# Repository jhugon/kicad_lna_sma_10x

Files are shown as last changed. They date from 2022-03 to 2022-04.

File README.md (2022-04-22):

# Low Noise Amplifier SMA 10x Board in KiCAD

This KiCad board is a low noise amplifier with SMA input and output.

- 100 kHz to 20 MHz
- 10 times amplitude amplification
- ≤ 100 µV RMS noise
- AC coupled input

## Notes on Performance as-built

I've been setting +/- 5 V supplies, 20 mA current limit, with +/- 6V OVP and 25 mA OCP.

- Idle current: 9 mA with +/- 5 V supplies
- Current draw rises above 20 mA for large signals
- Noise 1478 µV RMS at output (without subtracting noise floor), with a broad bump around 8-10 MHz in the FFT
- In trying to analyze with a square wave, the AC-coupling low-pass filter frequency seems
  quite high compared to the bandwidth. Maybe it should be at 10 kHz instead of
  100 kHz?
- Sin response:
    - Gain peaks ~ 9 MHz at 17 dB
    - Gain -3 dB from peak a little above 10 MHz
- Step response:
    - 10-90% rise time: 22 ns
    - 0-99% rise time: 32 ns
    - Overshoot: 28%
    - 1 pct settling time: ~200 ns
- Hooked up to SiPM and LED pulser:
    - Detect pulses with 10s of mV peak heights
    - Ringing is evident, lasts ~ 250 ns
    - Pulse width 50-100 ns
    - Can't see pulse height quantization, it's just one big smeared gaussian

With 10 pF (leaded) decoupling cap soldered between U1 output and inverting input:

- Noise a bit lower than before; FFT is flat compared to a broad, low peak around 20 MHz before
- Sin response:
    - Gain max ~flat between 400 kHz and 100 MHz
    - Gain -3 dB from peak at 100 kHz and 3 MHz
- Step response:
    - Minimal overshoot/settling, probably overdamped now
    - 10-90% rise time: 112 ns
    - 0-99% rise time: 293 ns
    - Overshoot: <1%
    - 1 pct settling time: ~250 ns
- Hooked up to SiPM and LED pulser:
    - Pulse height seems lower than before
    - No ringing, maybe baseline is a bit lower on tail
    - Pulse width 100-150 ns
    - Can't see pulse height quantization, it's just one big smeared gaussian

## To-Do

- Decoupling cap(s) from V+ to V-?
- Compensation cap between gain-amp out and in-?
- Lower input blocking filter freq?
- Forgot about factor of 1/2 from 50 Ohm termination voltage divider--need extra factor of 2 gain
- Add input/output labels on SMAs
- Add +/- signs on DC in
- SMA terminator for noise measurements

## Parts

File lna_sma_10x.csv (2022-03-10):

Source: | /home/jhugon/kicad/lna_sma_10x/lna_sma_10x.kicad_sch
Date: | Thu 10 Mar 2022 11:07:08 AM CST
Tool: | Eeschema 6.0.2-378541a8eb~116~ubuntu20.04.1
Generator: | /usr/share/kicad/plugins/bom_csv_grouped_by_value.py
Component Count: | 20
Individual Components:
Item | Qty | Reference(s) | Value | LibPart | Footprint | Datasheet | Mfr | Mfr Part | Tol/Type
 |  | C1 | 10u | Device:C | Capacitor_SMD:C_1206_3216Metric_Pad1.33x1.80mm_HandSolder | https://www.mouser.com/datasheet/2/585/MLCC-1837944.pdf | Samsung | CL31A106KAHNNNF | 5%/X5R
 |  | C2 | 160p | Device:C | Capacitor_SMD:C_1206_3216Metric_Pad1.33x1.80mm_HandSolder | https://www.mouser.com/datasheet/2/40/C0GNP0_Dielectric-951274.pdf | Kyocera AVX | 12065A161JAT2A | 5%/C0G
 |  | C3 | 0.1u | Device:C | Capacitor_SMD:C_1206_3216Metric_Pad1.33x1.80mm_HandSolder | https://www.mouser.com/datasheet/2/585/MLCC-1837944.pdf | Samsung | CL31B104KBCNNND | 5%/X5R
 |  | C4 | 0.1u | Device:C | Capacitor_SMD:C_1206_3216Metric_Pad1.33x1.80mm_HandSolder | https://www.mouser.com/datasheet/2/585/MLCC-1837944.pdf | Samsung | CL31B104KBCNNND | 5%/X5R
 |  | C5 | 10u | Device:C | Capacitor_SMD:C_1206_3216Metric_Pad1.33x1.80mm_HandSolder | https://www.mouser.com/datasheet/2/585/MLCC-1837944.pdf | Samsung | CL31A106KAHNNNF | 5%/X5R
 |  | C6 | 0.1u | Device:C | Capacitor_SMD:C_1206_3216Metric_Pad1.33x1.80mm_HandSolder | https://www.mouser.com/datasheet/2/585/MLCC-1837944.pdf | Samsung | CL31B104KBCNNND | 5%/X5R
 |  | C7 | 0.1u | Device:C | Capacitor_SMD:C_1206_3216Metric_Pad1.33x1.80mm_HandSolder | https://www.mouser.com/datasheet/2/585/MLCC-1837944.pdf | Samsung | CL31B104KBCNNND | 5%/X5R
 |  | J1 | Conn_Coaxial | Connector:Conn_Coaxial | Connector_Coaxial:SMA_Amphenol_132289_EdgeMount | https://www.mouser.com/datasheet/2/18/1/amphs06501_1-2259276.pdf | Amphenol | 132289
 |  | J2 | Power In | New_Library:Power-NanoFit-01x03 | Connector_Molex:Molex_Nano-Fit_105313-xx03_1x03_P2.50mm_Horizontal | https://www.mouser.com/datasheet/2/276/1/1053131303_PCB_HEADERS-1373923.pdf | Molex | 105313-1303
 |  | J3 | Conn_Coaxial | Connector:Conn_Coaxial | Connector_Coaxial:SMA_Amphenol_132289_EdgeMount | https://www.mouser.com/datasheet/2/18/1/amphs06501_1-2259276.pdf | Amphenol | 132289
 |  | R1 | 10K | Device:R_US | Resistor_SMD:R_1206_3216Metric_Pad1.30x1.75mm_HandSolder | https://www.mouser.com/datasheet/2/427/crcwce3-1762584.pdf | Vishay | CRCW120610K0FKEBC | 1%
 |  | R2 | 10K | Device:R_US | Resistor_SMD:R_1206_3216Metric_Pad1.30x1.75mm_HandSolder | https://www.mouser.com/datasheet/2/427/crcwce3-1762584.pdf | Vishay | CRCW120610K0FKEBC | 1%
 |  | R3 | 50R | Device:R_US | Resistor_SMD:R_1206_3216Metric_Pad1.30x1.75mm_HandSolder | https://www.mouser.com/datasheet/2/427/crcwce3-1762584.pdf | Vishay | CRCW120649R9FKEAC | 5%
 |  | R4 | 500R | Device:R_US | Resistor_SMD:R_1206_3216Metric_Pad1.30x1.75mm_HandSolder | https://www.mouser.com/datasheet/2/427/crcwce3-1762584.pdf | Vishay | CRCW1206499RFKEAC | 1%
 |  | R5 | 3K3 | Device:R_US | Resistor_SMD:R_1206_3216Metric_Pad1.30x1.75mm_HandSolder | https://www.mouser.com/datasheet/2/427/crcwce3-1762584.pdf | Vishay | CRCW12063K32FKEAC | 1%
 |  | R6 | 100R | Device:R_US | Resistor_SMD:R_1206_3216Metric_Pad1.30x1.75mm_HandSolder | https://www.mouser.com/datasheet/2/427/crcwce3-1762584.pdf | Vishay | CRCW1206100RFKEAC | 5%
 |  | R7 | 1k2 | Device:R_US | Resistor_SMD:R_1206_3216Metric_Pad1.30x1.75mm_HandSolder | https://www.mouser.com/datasheet/2/427/crcwce3-1762584.pdf | Vishay | CRCW12061K20FKEAC | 1%
 |  | R8 | 50R | Device:R_US | Resistor_SMD:R_1206_3216Metric_Pad1.30x1.75mm_HandSolder | https://www.mouser.com/datasheet/2/427/crcwce3-1762584.pdf | Vishay | CRCW120649R9FKEAC | 5%
 |  | U1 | LT1722xS8 | New_Library:LT1722xS8 | Package_SO:SOIC-8_3.9x4.9mm_P1.27mm | https://www.analog.com/media/en/technical-documentation/data-sheets/172234fb.pdf | Analog Devices | LT1722CS8#PBF
 |  | U2 | BUF602xD | Amplifier_Buffer:BUF602xD | Package_SO:SOIC-8_3.9x4.9mm_P1.27mm | http://www.ti.com/lit/ds/symlink/buf602.pdf | Texas Instruments | BUF602ID
Collated Components:
Item | Qty | Reference(s) | Value | LibPart | Footprint | Datasheet | Mfr | Mfr Part | Tol/Type
1 | 2 | C1, C5 | 10u | Device:C | Capacitor_SMD:C_1206_3216Metric_Pad1.33x1.80mm_HandSolder | https://www.mouser.com/datasheet/2/585/MLCC-1837944.pdf | Samsung | CL31A106KAHNNNF | 5%/X5R
2 | 1 | C2 | 160p | Device:C | Capacitor_SMD:C_1206_3216Metric_Pad1.33x1.80mm_HandSolder | https://www.mouser.com/datasheet/2/40/C0GNP0_Dielectric-951274.pdf | Kyocera AVX | 12065A161JAT2A | 5%/C0G
3 | 4 | C3, C4, C6, C7 | 0.1u | Device:C | Capacitor_SMD:C_1206_3216Metric_Pad1.33x1.80mm_HandSolder | https://www.mouser.com/datasheet/2/585/MLCC-1837944.pdf | Samsung | CL31B104KBCNNND | 5%/X5R
4 | 2 | J1, J3 | Conn_Coaxial | Connector:Conn_Coaxial | Connector_Coaxial:SMA_Amphenol_132289_EdgeMount | https://www.mouser.com/datasheet/2/18/1/amphs06501_1-2259276.pdf | Amphenol | 132289
5 | 1 | J2 | Power In | New_Library:Power-NanoFit-01x03 | Connector_Molex:Molex_Nano-Fit_105313-xx03_1x03_P2.50mm_Horizontal | https://www.mouser.com/datasheet/2/276/1/1053131303_PCB_HEADERS-1373923.pdf | Molex | 105313-1303
6 | 2 | R1, R2 | 10K | Device:R_US | Resistor_SMD:R_1206_3216Metric_Pad1.30x1.75mm_HandSolder | https://www.mouser.com/datasheet/2/427/crcwce3-1762584.pdf | Vishay | CRCW120610K0FKEBC | 1%
7 | 2 | R3, R8 | 50R | Device:R_US | Resistor_SMD:R_1206_3216Metric_Pad1.30x1.75mm_HandSolder | https://www.mouser.com/datasheet/2/427/crcwce3-1762584.pdf | Vishay | CRCW120649R9FKEAC | 5%
8 | 1 | R4 | 500R | Device:R_US | Resistor_SMD:R_1206_3216Metric_Pad1.30x1.75mm_HandSolder | https://www.mouser.com/datasheet/2/427/crcwce3-1762584.pdf | Vishay | CRCW1206499RFKEAC | 1%
9 | 1 | R5 | 3K3 | Device:R_US | Resistor_SMD:R_1206_3216Metric_Pad1.30x1.75mm_HandSolder | https://www.mouser.com/datasheet/2/427/crcwce3-1762584.pdf | Vishay | CRCW12063K32FKEAC | 1%
10 | 1 | R6 | 100R | Device:R_US | Resistor_SMD:R_1206_3216Metric_Pad1.30x1.75mm_HandSolder | https://www.mouser.com/datasheet/2/427/crcwce3-1762584.pdf | Vishay | CRCW1206100RFKEAC | 5%
11 | 1 | R7 | 1k2 | Device:R_US | Resistor_SMD:R_1206_3216Metric_Pad1.30x1.75mm_HandSolder | https://www.mouser.com/datasheet/2/427/crcwce3-1762584.pdf | Vishay | CRCW12061K20FKEAC | 1%
12 | 1 | U1 | LT1722xS8 | New_Library:LT1722xS8 | Package_SO:SOIC-8_3.9x4.9mm_P1.27mm | https://www.analog.com/media/en/technical-documentation/data-sheets/172234fb.pdf | Analog Devices | LT1722CS8#PBF
13 | 1 | U2 | BUF602xD | Amplifier_Buffer:BUF602xD | Package_SO:SOIC-8_3.9x4.9mm_P1.27mm | http://www.ti.com/lit/ds/symlink/buf602.pdf | Texas Instruments | BUF602ID

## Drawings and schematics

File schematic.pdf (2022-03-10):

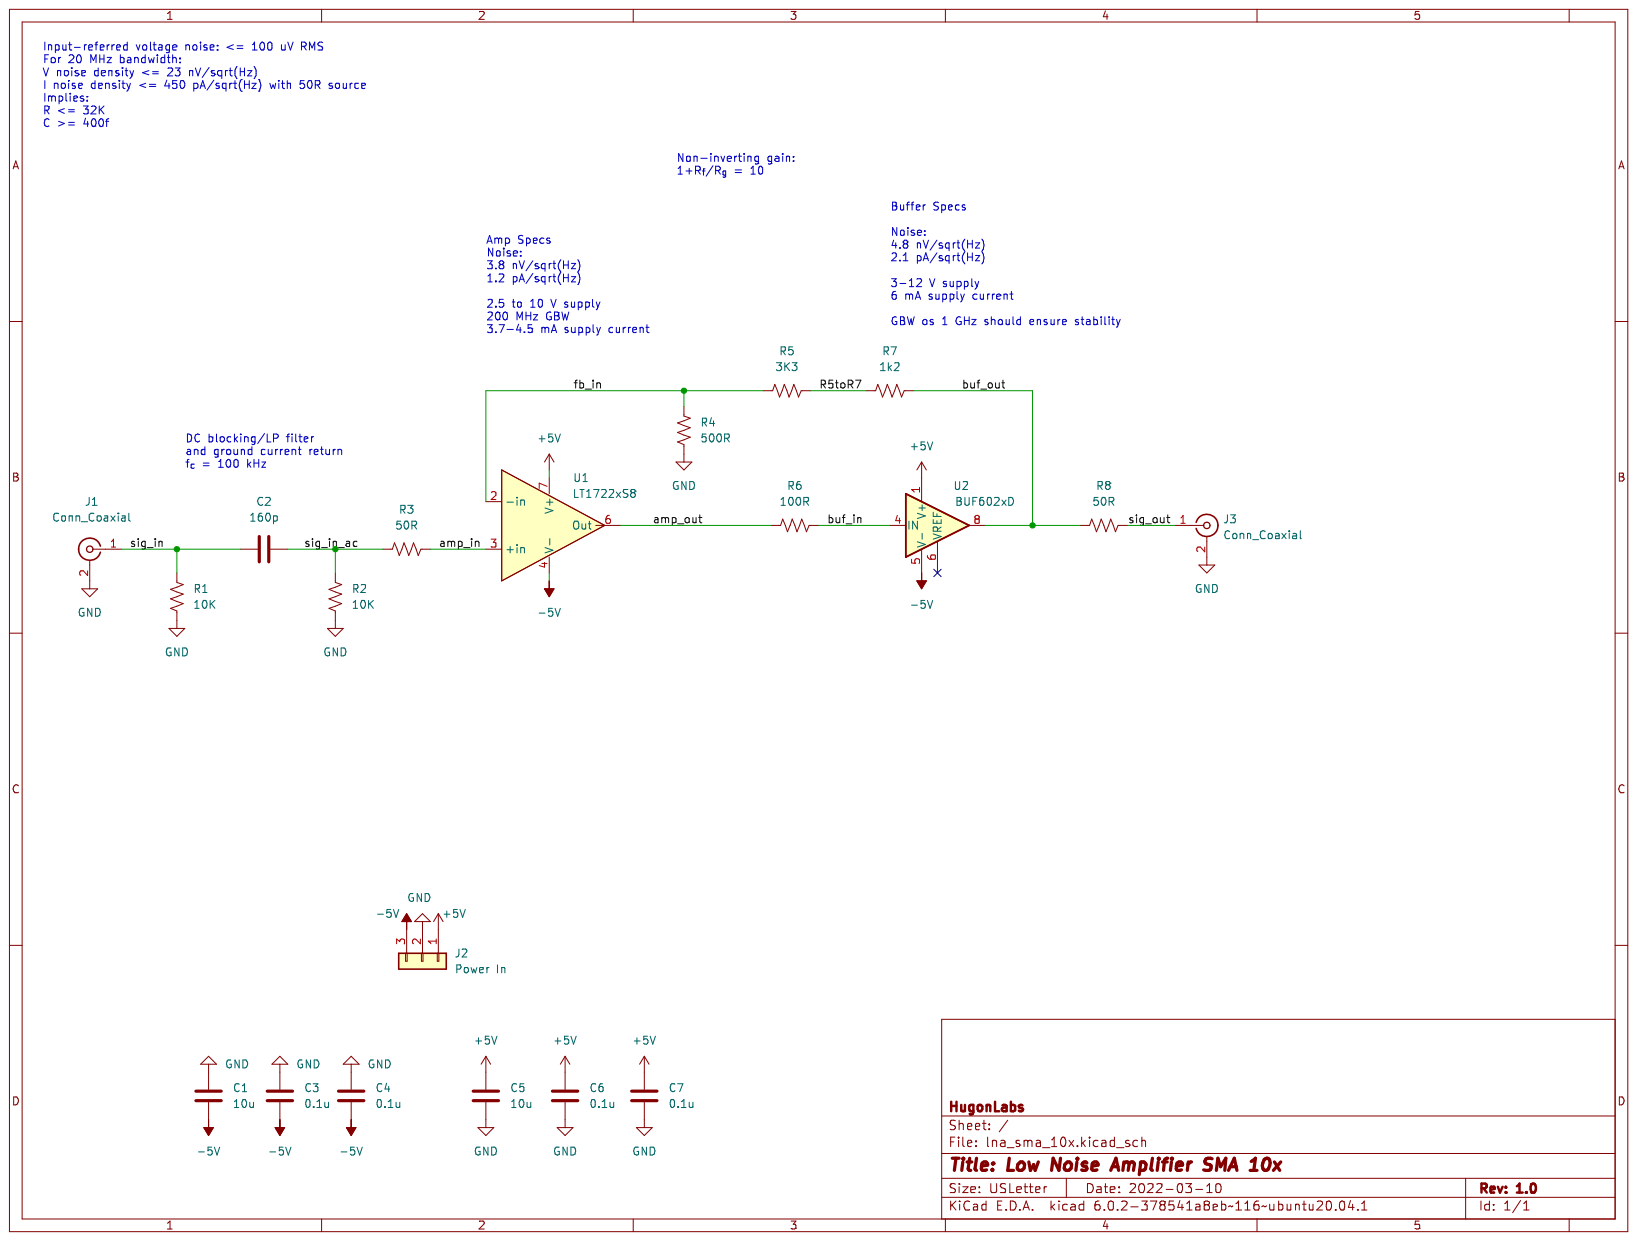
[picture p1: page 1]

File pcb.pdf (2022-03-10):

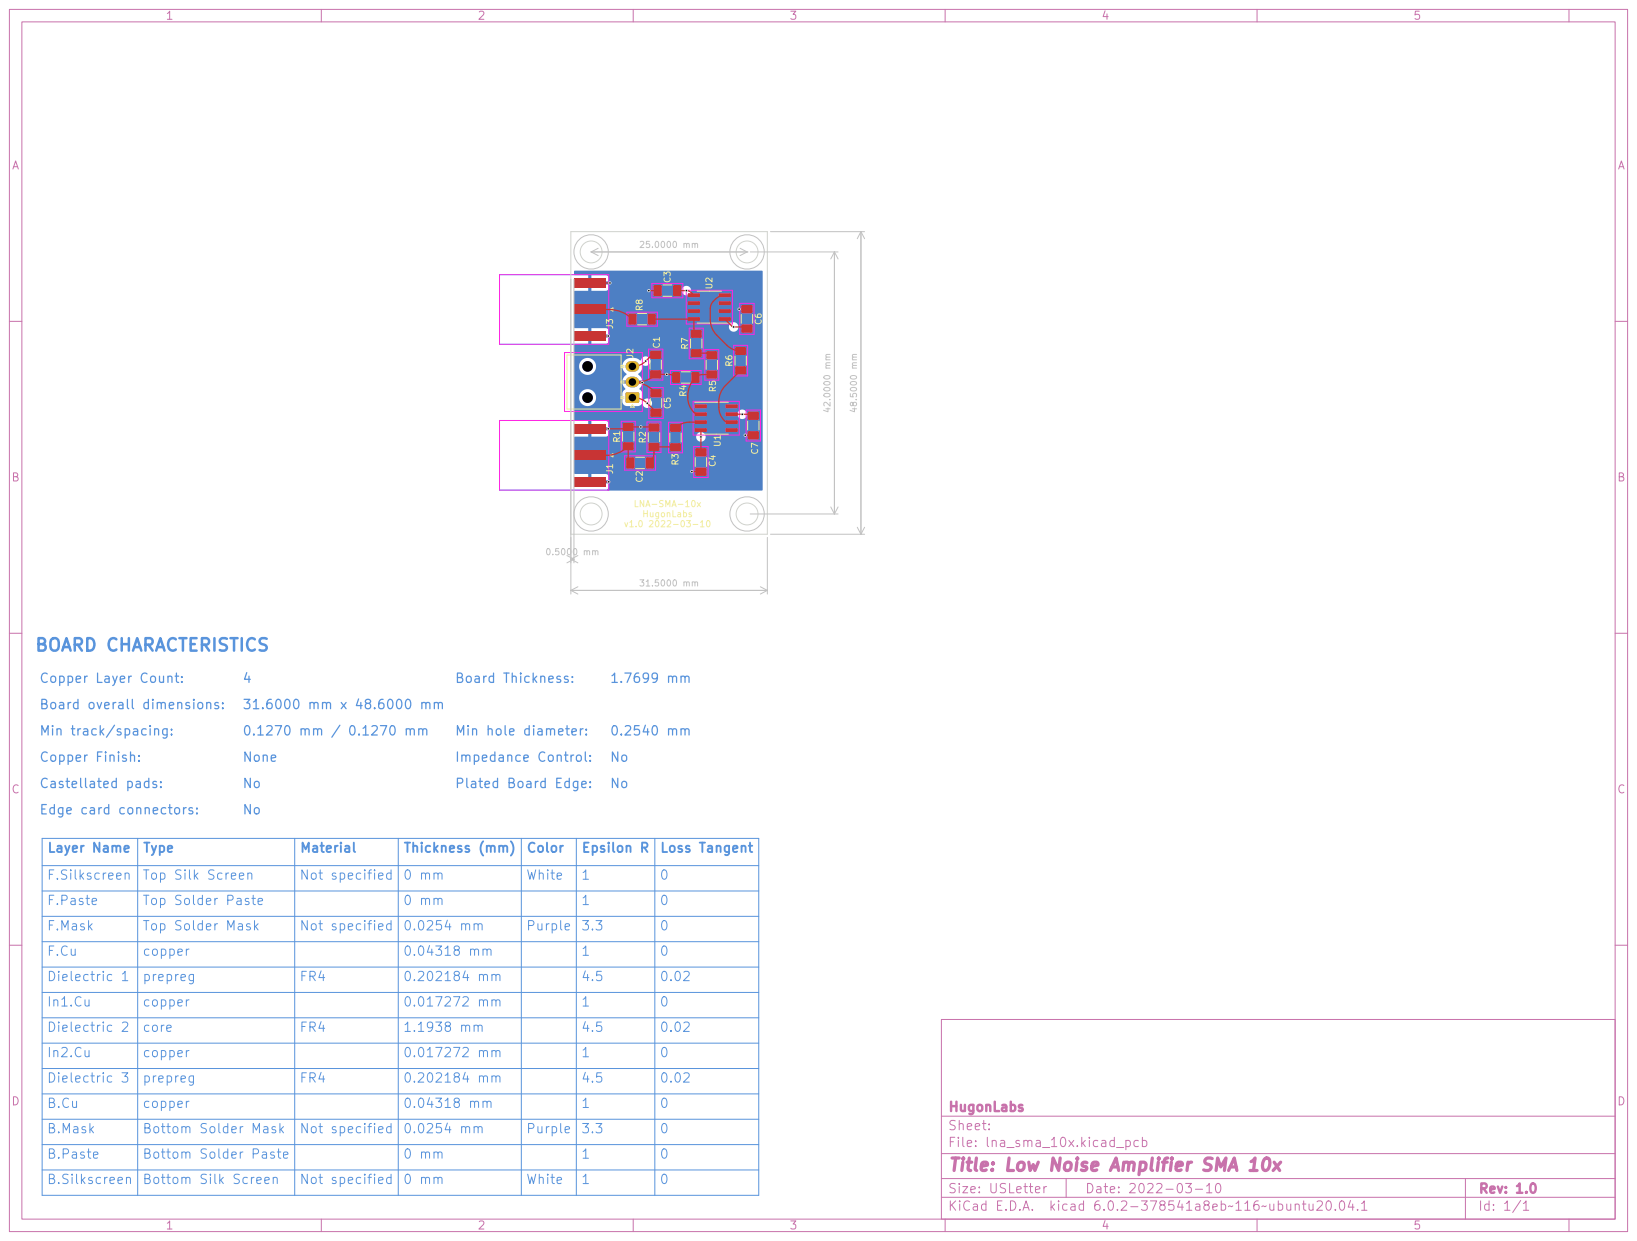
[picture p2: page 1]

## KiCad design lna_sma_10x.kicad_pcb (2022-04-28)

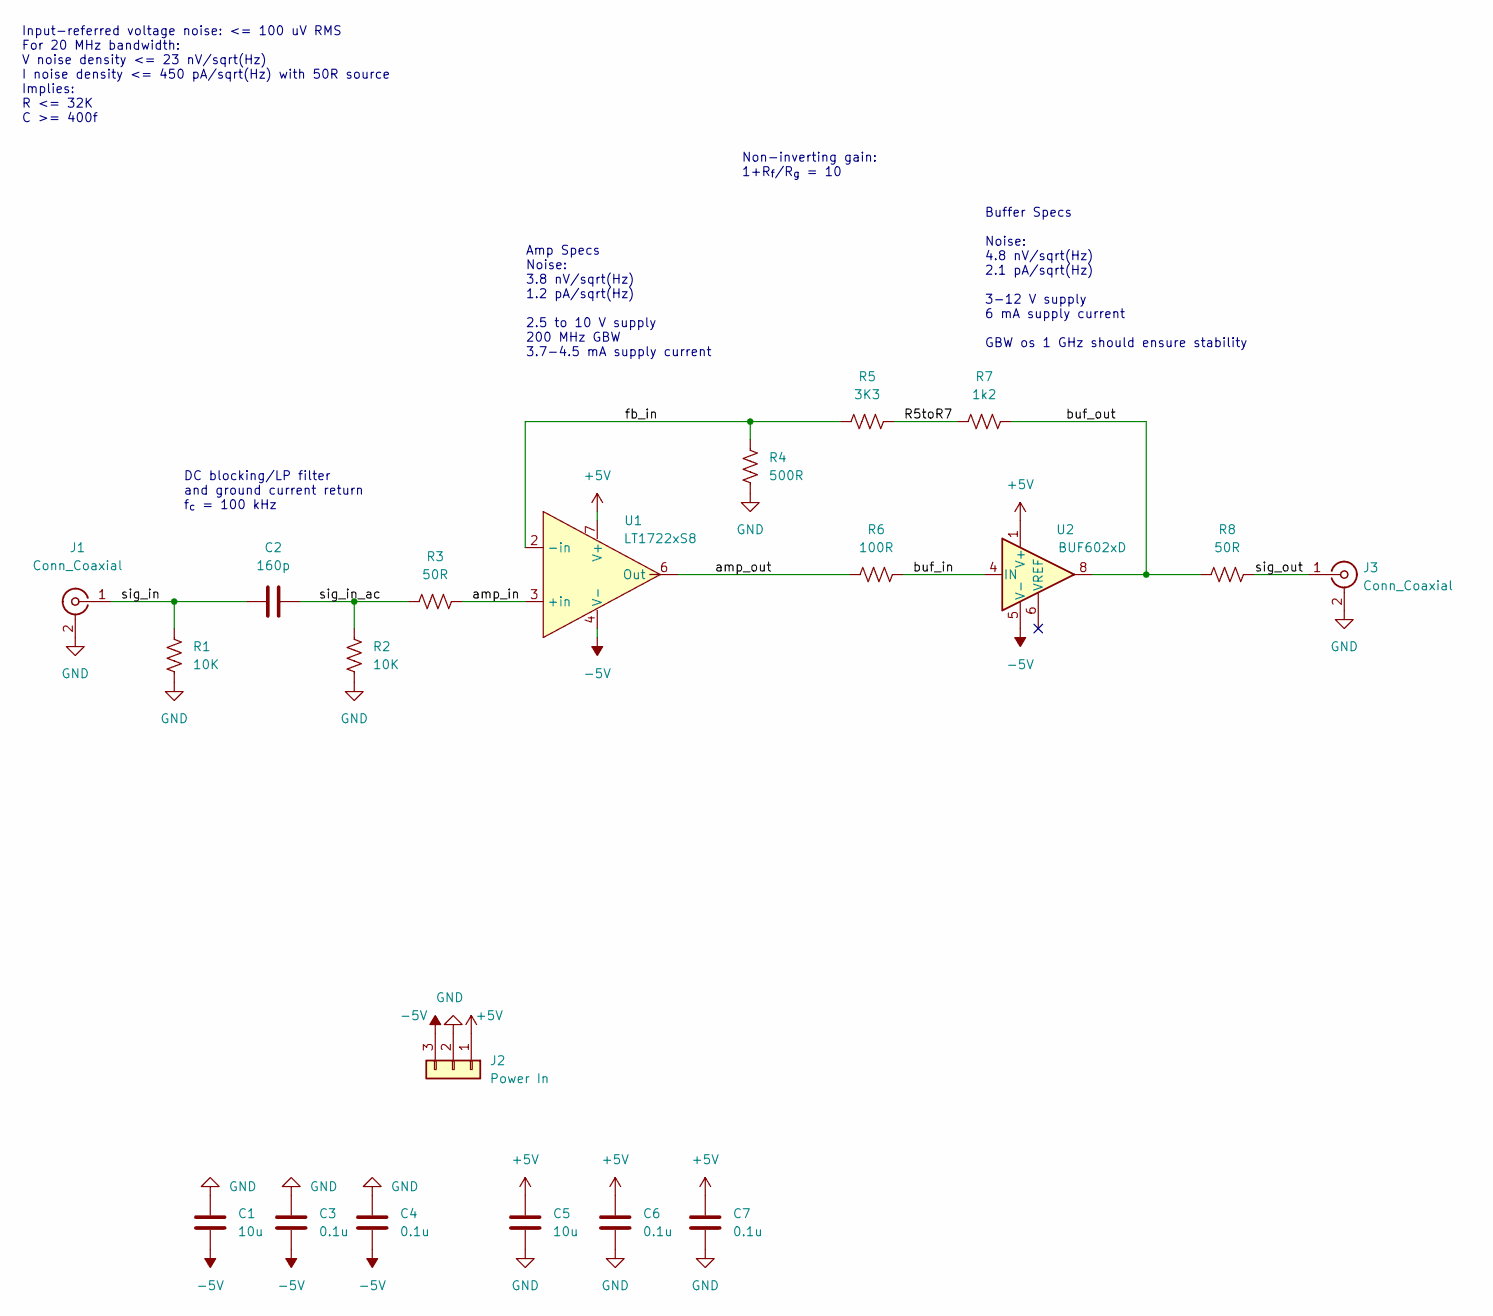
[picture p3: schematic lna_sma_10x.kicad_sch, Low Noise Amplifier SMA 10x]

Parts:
C1, C5: 10u; C_1206_3216Metric_Pad1.33x1.80mm_HandSolder; Mfr Part CL31A106KAHNNNF
C2: 160p; C_1206_3216Metric_Pad1.33x1.80mm_HandSolder; Mfr Part 12065A161JAT2A
C3, C4, C6, C7: 0.1u; C_1206_3216Metric_Pad1.33x1.80mm_HandSolder; Mfr Part CL31B104KBCNNND
J1, J3: Conn_Coaxial; SMA_Amphenol_132289_EdgeMount; Mfr Part 132289
J2: Power In; Molex_Nano-Fit_105313-xx03_1x03_P2.50mm_Horizontal; Mfr Part 105313-1303
R1, R2: 10K; R_1206_3216Metric_Pad1.30x1.75mm_HandSolder; Mfr Part CRCW120610K0FKEBC
R3, R8: 50R; R_1206_3216Metric_Pad1.30x1.75mm_HandSolder; Mfr Part CRCW120649R9FKEAC
R4: 500R; R_1206_3216Metric_Pad1.30x1.75mm_HandSolder; Mfr Part CRCW1206499RFKEAC
R5: 3K3; R_1206_3216Metric_Pad1.30x1.75mm_HandSolder; Mfr Part CRCW12063K32FKEAC
R6: 100R; R_1206_3216Metric_Pad1.30x1.75mm_HandSolder; Mfr Part CRCW1206100RFKEAC
R7: 1k2; R_1206_3216Metric_Pad1.30x1.75mm_HandSolder; Mfr Part CRCW12061K20FKEAC
U1: LT1722xS8; SOIC-8_3.9x4.9mm_P1.27mm; Mfr Part LT1722CS8#PBF
U2: BUF602xD; SOIC-8_3.9x4.9mm_P1.27mm; Mfr Part BUF602ID

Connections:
+5V: C5.2, C6.2, C7.2, J2.1, U1.7 (V+), U2.1 (V+)
-5V: C1.1, C3.1, C4.1, J2.3, U1.4 (V-), U2.5 (V-)
/R5toR7: R5.2, R7.1
/amp_in: R3.2, U1.3 (+in)
/amp_out: R6.1, U1.6 (Out)
/buf_in: R6.2, U2.4 (IN)
/buf_out: R7.2, R8.1, U2.8
/fb_in: R4.2, R5.1, U1.2 (-in)
/sig_in: C2.1, J1.1 (In), R1.1
/sig_in_ac: C2.2, R2.1, R3.1
/sig_out: J3.1 (In), R8.2
GND: C1.2, C3.2, C4.2, C5.1, C6.1, C7.1, J1.2 (Ext), J2.2, J3.2 (Ext), R1.2, R2.2, R4.1

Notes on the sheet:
Amp Specs Noise: 3.8 nV/sqrt(Hz) 1.2 pA/sqrt(Hz) 2.5 to 10 V supply 200 MHz GBW 3.7-4.5 mA supply current
DC blocking/LP filter and ground current return f_{c} = 100 kHz
Non-inverting gain: 1+R_{f}/R_{g} = 10
Buffer Specs Noise: 4.8 nV/sqrt(Hz) 2.1 pA/sqrt(Hz) 3-12 V supply 6 mA supply current GBW os 1 GHz should ensure stability
Input-referred voltage noise: <= 100 uV RMS For 20 MHz bandwidth: V noise density <= 23 nV/sqrt(Hz) I noise density <= 450 pA/sqrt(Hz) with 50R source Implies: R <= 32K C >= 400f

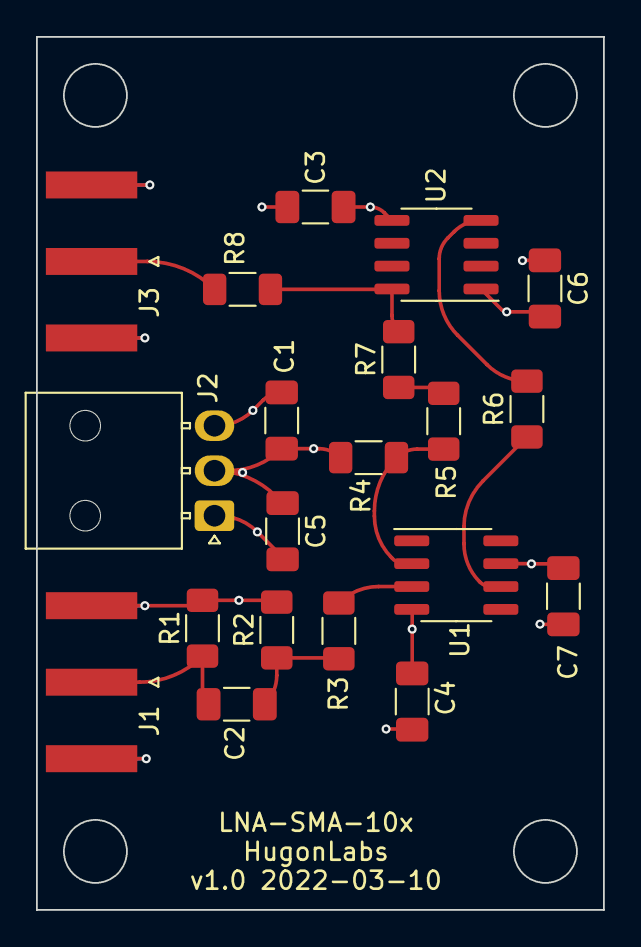
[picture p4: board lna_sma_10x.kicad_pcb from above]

Board: 4 copper layers, 31.5 x 48.5 mm, 20 parts (0 on the bottom side), 12 nets.

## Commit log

2022-03-03 Initial schematic complete
    added New_Library with LT1722
    added schematic.pdf
    [lna_sma_10x.kicad_sch]
2022-03-10 Schematic & BOM complete
    Split feedback R into 2 in series to get standard values
    Added power connector to library to have output power pins
    Added part numbers, data sheets, footprints in BOM
    [lna_sma_10x.csv, lna_sma_10x.kicad_sch]
2022-03-10 PCB Placement, setup for 4 layers
    [lna_sma_10x.kicad_pcb, lna_sma_10x.kicad_sch]
2022-03-10 Defined PCB edges and holes
    [lna_sma_10x.kicad_pcb]
2022-03-10 PCB routed and planes filled
    [lna_sma_10x.kicad_pcb]
2022-03-10 completed silkscreen and bumped to 1.0
    [lna_sma_10x.csv, lna_sma_10x.kicad_pcb, lna_sma_10x.kicad_sch]
2022-03-10 Generated gerbers for v1.0--final
    [lna_sma_10x-B_Cu.gbl, lna_sma_10x-B_Mask.gbs, lna_sma_10x-B_Paste.gbp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]
2022-04-28 now use git submodule kicad_hugonlib for libs
    moved power nano-fit over there and deleted New_Library
    [lna_sma_10x.kicad_pcb, lna_sma_10x.kicad_sch]
